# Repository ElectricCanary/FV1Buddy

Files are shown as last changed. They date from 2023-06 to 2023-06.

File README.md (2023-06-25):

# FV1Buddy

THIS PROJECT IS ONLY PARTIALLY WORKING FOR NOW

The FV1Buddy is a Tap Tempo & Clock Module for the Spin Semiconductor FV1 DSP.

You'll find the main code in C, the compiled hex, a datasheet and Altium & Eagle libraries.

Website : https://electric-canary.com/fv1buddy

Support : support@electric-canary.com

The Code, Schematic and PCB manufacturing files are shared under a BY-NC-SA Creative Commons License

Go here for complete license : https://creativecommons.org/licenses/by-nc-sa/4.0/legalcode

Please reach out for licencing if you want to use the code in a commercial product. 

FV1Buddy

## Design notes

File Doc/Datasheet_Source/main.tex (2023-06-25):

\documentclass[a4paper, 10pt]{article}

\usepackage[default]{comfortaa}
\usepackage[utf8]{inputenc}
\usepackage[english]{babel}
\usepackage{graphicx}
\usepackage{geometry}
\usepackage{titlesec}
\usepackage{multicol}
\usepackage{lastpage}
\usepackage{fancyhdr}
\usepackage{array}
\usepackage{multirow, hhline}
\usepackage[table]{xcolor}
\usepackage[hidelinks]{hyperref}
\usepackage{textcomp}

\setlength{\columnseprule}{1pt}
\setlength{\columnsep}{1cm}

\definecolor{lightgray}{gray}{0.85}

\setlength{\arrayrulewidth}{0.35mm}
\setlength{\tabcolsep}{10pt}
\renewcommand{\arraystretch}{1.7}

\fancypagestyle{plain}{%
\fancyhf{} % clear all header and footer fields
\cfoot{\thepage /\pageref{LastPage}}
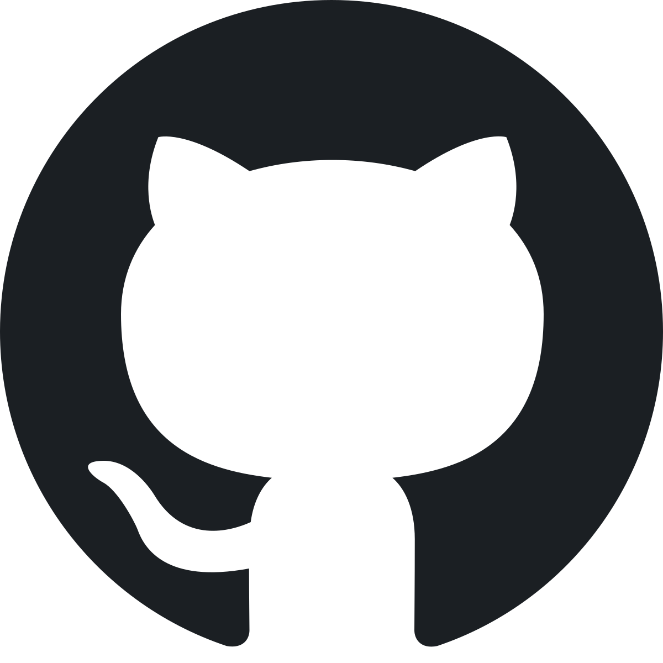
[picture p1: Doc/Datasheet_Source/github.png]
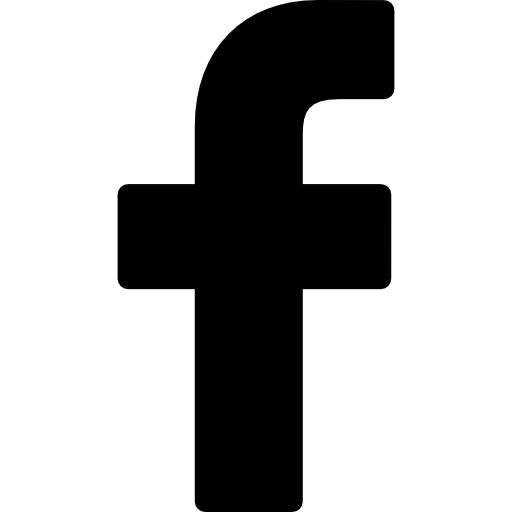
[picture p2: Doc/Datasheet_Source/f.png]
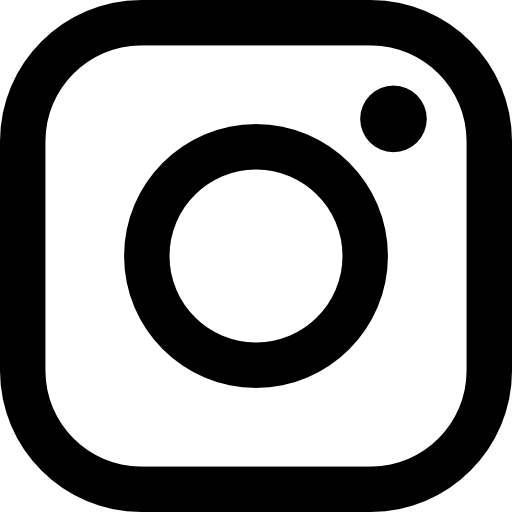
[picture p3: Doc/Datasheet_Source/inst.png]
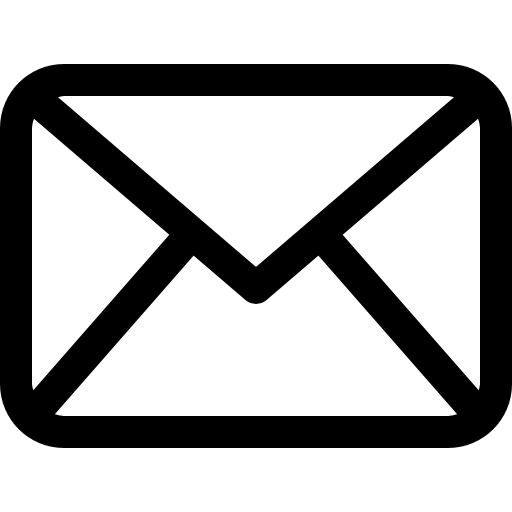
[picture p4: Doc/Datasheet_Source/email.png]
\rfoot{\href{https://github.com/ElectricCanary/FV1Buddy}{}\hspace{8pt}\href{https://www.facebook.com/ElectricCanary}{}\hspace{8pt}\href{https://www.instagram.com/electricanary/}{}\hspace{12pt}\href{mailto:support@electric-canary.com}{}}
\lfoot{\textcolor{black!70}{{\footnotesize\textcopyright Electric Canary - June 2022}}}
\renewcommand{\headrulewidth}{0pt}
\renewcommand{\footrulewidth}{0pt}}

\pagestyle{fancy}
\renewcommand{\headrulewidth}{0pt}
\cfoot{}
\cfoot{\thepage /\pageref{LastPage}}
\rfoot{\href{https://github.com/ElectricCanary/FV1Buddy}{}\hspace{8pt}\href{https://www.facebook.com/ElectricCanary}{}\hspace{8pt}\href{https://www.instagram.com/electricanary/}{}\hspace{12pt}\href{mailto:support@electric-canary.com}{}}
\lfoot{\textcolor{black!70}{{\footnotesize\textcopyright Electric Canary - June 2022}}}
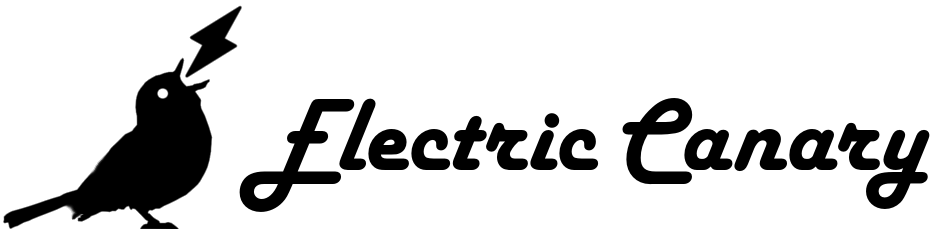
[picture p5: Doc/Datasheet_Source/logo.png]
\rhead{\href{https://electric-canary.com/FV1Buddy}{}}
\lhead{\textbf{{\small\emph{\textcolor{black!70}{FV1Buddy-Datasheet}}}}}

\titleformat*{\section}{\huge\bfseries}
\titleformat*{\subsection}{\LARGE\bfseries}
\titleformat*{\subsubsection}{\Large\bfseries}

\geometry{hmargin=2.5cm,vmargin=2.5cm}
\headheight=35pt

\begin{document}\thispagestyle{plain}
\begin{center}
\begin{Huge}
\vspace*{0.5cm}
\textbf{FV1Buddy - Datasheet}
\rule {0.95\textwidth}{2pt}\\
\end{Huge}
\vspace{1cm}
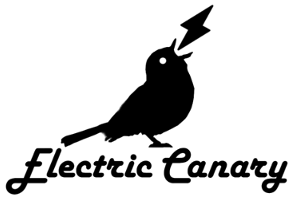
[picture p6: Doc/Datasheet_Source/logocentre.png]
\\
\end{center}
\vspace{1cm}
\begin{multicols}{2}
\section{Introduction}
\bigbreak

FV1Buddy is a Tap Tempo and Clock module for the Spin Semiconductor FV1 DSP.\\

This module is a great option for enabling tap tempo functionality in a FV1 based project.
The tap tempo is intuitive and has 6 different tempo divisions.\\
The clock output can also enhance the DSP's sound, unlike most circuits.\\
Other surprises like the momentary modulation and tempo save let's you enjoy your effects to the fullest.
\vfill\null
\columnbreak

\section{Features}
\bigbreak
\begin{itemize}
\item {Intuitive and Precise Tap Tempo}
\item \hyperref[subsec:tempodiv]{6 Selectable Tempo Divisions} \\  ,  ,  ,  ,  , 
\item \hyperref[sec:clock]{48kHz Clock for Better Audio}
\item \hyperref[sec:temposave]{Tempo EEPROM Save}
\item \hyperref[subsec:ramp]{Ramp Modulation Momentary Effect}
\item \hyperref[sec:pinconfig]{Compact DIP-8 Package}
\item \hyperref[sec:typappsche]{No External Parts}
\item \hyperref[sec:calib]{Adjustable Maximum Delay}
\end{itemize}
\end{multicols}

\newpage
\headheight=35pt
\tableofcontents
\newpage

\section{Pin Configuration}
\label{sec:pinconfig}
\vfill
\begin{center}
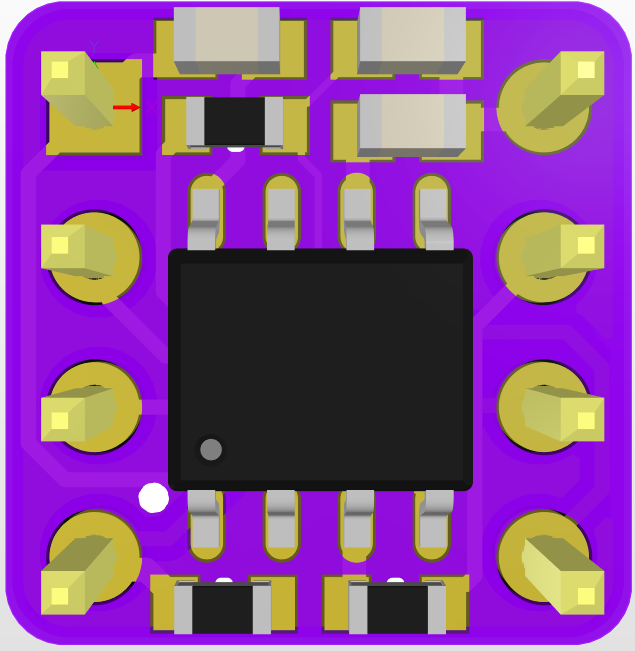
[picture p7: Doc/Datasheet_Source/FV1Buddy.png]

\vfill
\begin{table}[h!]
\begin{tabular}{|m{0.5cm}|m{4.5cm}|m{0.7cm}|m{7.5cm}|}
\hline
\rowcolor{lightgray} \centering {\Large\textbf{N°}} & \centering {\Large\textbf{Name}} & \centering {\Large\textbf{I/O}} & {\Large\textbf{Description}}\\
\hline
\centering 1 & \centering VCC & \centering I & Supply voltage.\\
\hline
\centering 2 & \centering Tap Button & \centering I & Set tempo when connected to ground.\\
\hline
\centering 3 & \centering Delay Time & \centering I & This pin's voltage determines the delay time when there's no tap sequence active.\\
\hline
\centering 4 & \centering Tempo Division Select & \centering I & This pin's voltage determines the tempo division selected.\\
\hline
\centering 5 & \centering Vout & \centering O & This pin can be connected to one of the pot pins of the FV1.\\
\hline
\centering 6 & \centering Clock Out & \centering O & 48kHz clock output for the FV1.\\
\hline
\centering 7 & \centering LED+ & \centering O & LED Indicator Output.\\
\hline
\centering 8 & \centering GND & \centering I & Ground.\\
\hline
\end{tabular}
\caption{Pin Configuration}
\end{table}
\end{center}
\vfill
\newpage

\section{Typical Application Schematic}
\label{sec:typappsche}
\bigbreak
This schematic shows how to implement the FV1Buddy into a simple delay project.
\vfill
\begin{figure} [h!]
\begin{center}

\label{Schem}
\caption{Typical Application Schematic}
\end{center}
\end{figure}
\vfill
\newpage
\section{Absolute Maximum Ratings}
\bigbreak
\begin{table}[h!]
\centering
\begin{tabular}{|c|c|}
\hline
Storage Temperature	& -65°C to +150°C\\
\hline
Operating Temperature & -40°C to +105°C\\
\hline
Voltage on any pin except pin 6	& -0.5V to Vcc + 0.5V\\
\hline
Voltage on Pin 6 & -0.5V to +13.0V\\
\hline
Power Supply Voltage & -0.5V to +6.0V\\
\hline
I/O Pin sink/source current & -40 to 40mA\\
\hline
DC Current for a supply pin & 100.0mA\\
\hline
\end{tabular}
\caption{Absolute Maximum Ratings}
\end{table}
\bigbreak
\bigbreak
\section{DC Characteristics}
\bigbreak
\begin{table}[h!]
\centering
\begin{tabular}{|c|c|c|c|}
\hline
\rowcolor{lightgray}{\Large\textbf{Parameter}} & {\Large\textbf{Min}} & {\Large\textbf{Max}} & {\Large\textbf{Unit}}\\
\hline
Power Supply Voltage & 1.8 & 5.5 & V\\
\hline
Power Supply Current & 5.8 & 7 & mA\\
\hline
\end{tabular}
\caption{DC Characteristics}
\end{table}
\bigbreak
For any other DC characteristics please refer to the ATtiny402 \href{http://ww1.microchip.com/downloads/en/DeviceDoc/ATtiny202-402-AVR-MCU-with-Core-Independent-Peripherals_and-picoPower-40001969A.pdf}{\underline{datasheet}} (p.476).
\bigbreak
\bigbreak
\section{Specifications}

\begin{table}[h!]
\centering
\begin{tabular}{|c|c|c|c|}
\hline
\rowcolor{lightgray}{\Large\textbf{Parameter}} & {\Large\textbf{Min}} & {\Large\textbf{Max}} & {\Large\textbf{Unit}}\\
\hline
Delay Time & 0 & 1000 & ms\\
\hline
PWM frequency & - & 20 & kHz\\
\hline
Clock frequency & - & 48 & kHz\\
\hline
All Potentiometer/Toggle Input & 0 & Vcc & V\\
\hline
\end{tabular}
\caption{Specifications}
\end{table}

All specifications tested at VCC = 3.3V.

\section{Power Supply}
\bigbreak
In order to function properly the module \textbf{must} be powered from the same 3.3V power supply than the FV1. Any voltage difference between the FV1Buddy and the FV1 power supplies will introduce some time error between the tap tempo and the delay.
A 0.1$\mu$F capacitor between Vcc and GND is already included in the module. Additional decoupling shouldn't be necessary.\\

\section{Calibration}
\label{sec:calib}
\bigbreak
The FV1Buddy comes with a 1000ms maximum delay. However some FV1 delay programs have a smaller maximum delay to accommodate the FV1 performance characteristics.\\
The FV1Buddy module maximum delay can be adjusted to 700, 800, 900 or 1000 ms.\\

To to calibrate the FV1Buddy, follow these instructions :\\
\begin{itemize}
\item Make sure the module is powered down.
\item Position the Time potentiometer to the desired maximum delay.
\item Minimum for 700ms, 10 o'clock for 800ms, 2 o'clock for 900ms, maximum for 1000ms.
\item Press the Tap Button.
\item Power Up the FV1Buddy while keeping the Tap Button Pressed.
\item Keep the button pressed while the Tempo LED blinks twice.
\item Release the Tap Button.
\item The LED blinks twice, the module is now calibrated to the new maximum delay.\\
\end{itemize}

\newpage
\section{Controls}
\subsection{Tap Tempo Button}
\bigbreak
This input is only compatible with a momentary switch.
The debounce is handled by software and with a 0.1$\mu$F capacitor in parallel to the Switch. No extra external components have to be used.\\

The program starts counting milliseconds after the first press. The delay time tapped is in effect right after the second press of the tap button. After the second press of the tap button, every following tap in the sequence is averaged in order to reach easily the desired tempo. 

If the button is not pressed again after a certain time ,the timer is reset and the tap sequence is ended. When a tap sequence has started, it will take 2 pulsations to be finished (the LED will start blinking on its own).\\

If the tap tempo button is pressed only once, the tap sequence will be aborted after the reset time passed.\\
The reset time follows this equation: $\frac{Max Delay}{Tempo Div Mult} + 800 = Reset Time (ms)$\\

Max Delay is either 1000, 900, 800 or 700ms. Tempo Div Mult is the multiplier of the current time division (1, 0.75, 0.5, 0.33, 0.25, 0.17).\\

When the tap tempo is active, the tempo LED will blink with the rhythm you tapped, regardless of the selected tempo division.\\

\subsection{Delay Time}
\label{subsec:delaytime}
\bigbreak
This input is to voltage control the delay time. This input will control the delay time until you activate the tap tempo. While the delay time is controlled by this input, the Tempo LED and will stay on.\\

To take back control from the Tap Tempo, you just need to modify this input's voltage by 7\%. Typically, you would use a Potentiometer for the delay time control. The recommended potentiometer value is 10k$\Omega$ or above, to avoid having too much current going through the pin.\\

You can add a 0.1$\mu$F capacitor between the input and ground for smoother time changes.\\

\subsection{Tempo Division Select}
\label{subsec:tempodiv}
\bigbreak
Six different tempo division are accessible with this input. To access every time division a SPDT On-Off-On toggle switch is required.\\

The first three time divisions are fourth, dotted eighth and eighth. The last three time divisions are accessed by first pressing the tap button and then changing the toggle position while the tap button is pressed. The press will not count as a press for the tap tempo. The three last time divisions are triplet, sixteenth and sextuplet.\\

The time divisions are selected by changing the Tempo Div Select Pin's voltage (Pin 4).\\

If the time division is changed while the Tap Tempo is active, the delay time will be changed accordingly instantly.\\

On the module, the middle position is accessed by putting a 27k$\Omega$ resistor between pin 4 and ground.\\

\subsection{Ramp Modulation}
\label{subsec:ramp}
\bigbreak
A ramp modulation can be activated if the tap button is pressed more than 2 seconds.\\
The ramp will begin to ascend then will descend once the max delay is achieved.\\
The modulation speed can be controlled by moving the Time Potentiometer accordingly. The movements won't be taken into account once you release the tap button.\\

\section{Tempo Save}
\label{sec:temposave}
\bigbreak
When you tap a tempo it is saved on the FV1Buddy's EEPROM. This means that if you power down the FV1Buddy while a tap sequence is active, the module will resume this sequence when powered up. This is true even if some parameters are moved when the FV1Buddy is powered down.\\

\section{Vout}
\label{sec:vout}
\bigbreak
The voltage output of pin 5 is to be connected to one of the "pot" inputs of the FV1 DSP (pins 20, 21 \& 22).\\
This analog voltage is achieved by passing a 20kHz PWM through an onboard RC low-pass filter. The low-pass filter is composed of a 10k$\Omega$ resistor and a 10$\mu$F capacitor.\\

\section{Clock Output}
\label{sec:clock}
\bigbreak
The clock output of pin is to be connected to the "X1" pin of the FV1 DSP (pin 10).\\
The clock has a frequency of 48kHz and will expand the bandwidth of the DSP up to 24kHz comparing to a 15kHz bandwidth with an oscillator.\\
This change will be pretty noticeable and help you fully appreciate your audio effects.\\

\section{Tempo LED}
\label{sec:led}
\bigbreak
When the delay time is controlled by the Time Potentiometer the LED will stay on.\\
When tapping a tap sequence, the LED will blink exactly when you press the tap button, beginning with the second press.\\
When the Tap Tempo is active, the tempo LED will blink in sync with the tempo you tapped regardless of the tempo division selected.\\
A 1k$\Omega$ current limiting resistor is included on the module.

\end{document}

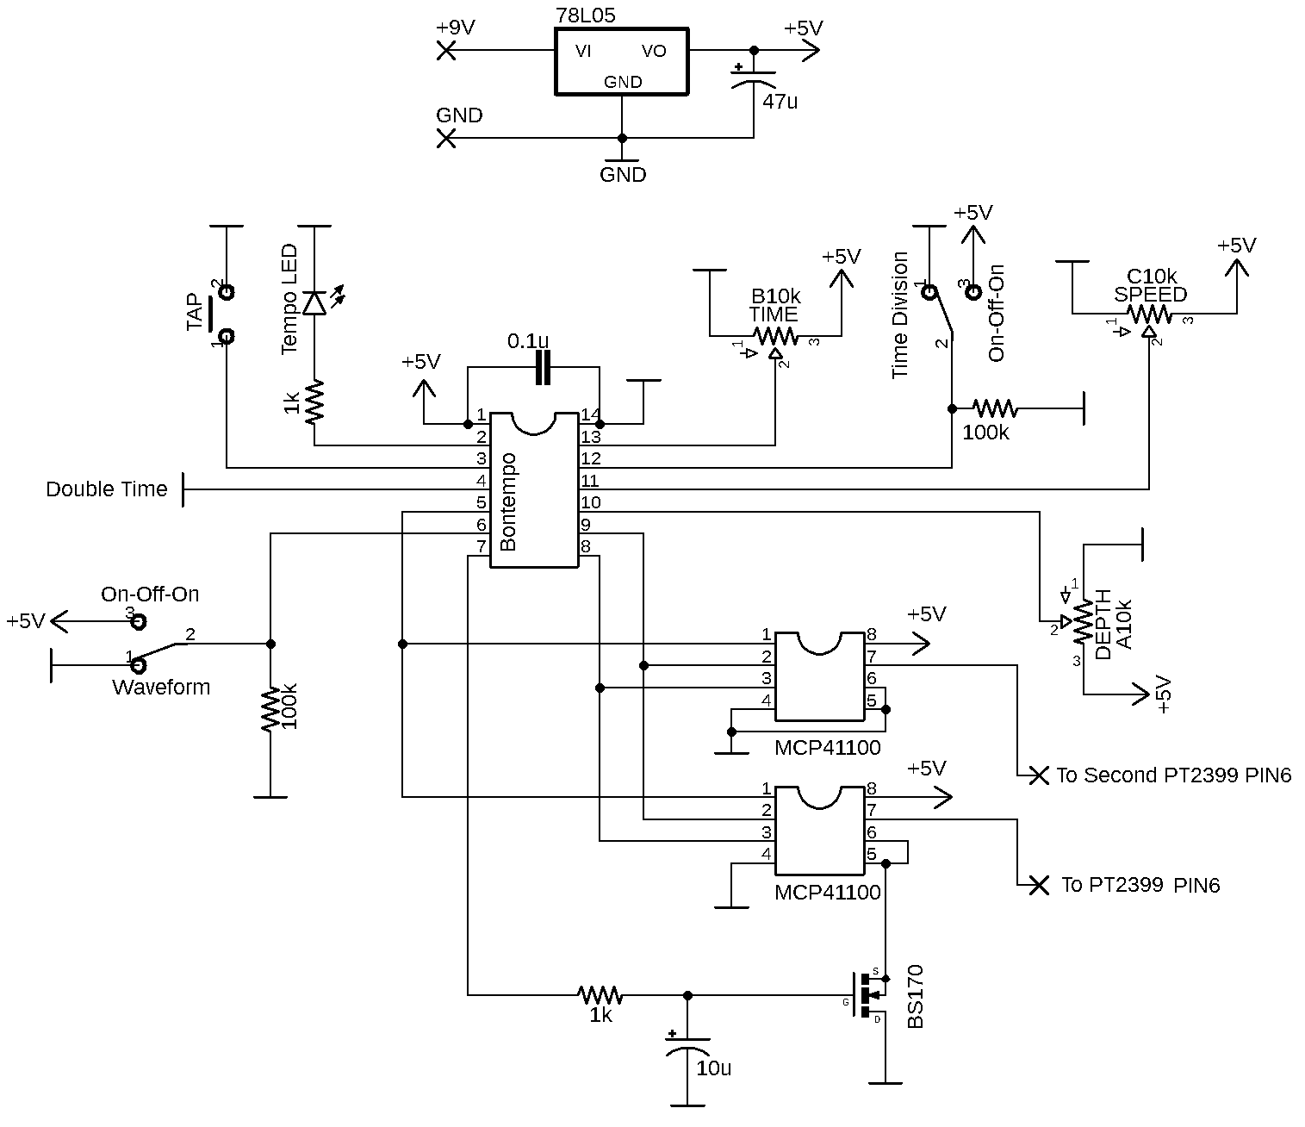
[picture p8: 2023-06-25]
Doc/Datasheet_Source/DualSchematic.png

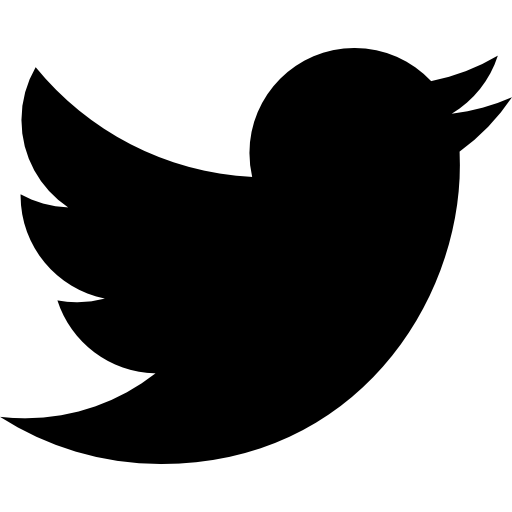
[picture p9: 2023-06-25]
Doc/Datasheet_Source/twitter.png

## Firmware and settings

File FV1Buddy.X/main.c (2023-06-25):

/* 
 * FV1 Buddy
 * January 2022
 * by Antoine Ricoux for Electric Canary
 * 
 *  https://electric-canary.com/FV1Buddy
 *  support@electric-canary.com
 * 
 * This code is an ATtiny402 Tap Tempo & Clock for the Spin Semiconductors FV1 DSP
 * It can be calibrated for 700, 800, 900 & 1000ms delays.
 * 
 * Pinout:
 * 1: VDD
 * 2: 48kHz Clock Output
 * 3: LED+ Output
 * 4: Time Potentiometer Analog Input
 * 5: Tempo Division Switch (On-Off-On) Analog Input
 * 6: Momentary Tap Tempo Button Input
 * 7: PWM Output
 * 8: GND
 * 
 * This code is shared shared under a BY-NC-SA Creative Commons License
 * Go here for complete license : https://creativecommons.org/licenses/by-nc-sa/4.0/legalcode
 */
#include <avr/io.h>
#include <avr/interrupt.h>
#define F_CPU 20000000UL
#include <util/delay.h>
#include <avr/eeprom.h>
#include <stdlib.h>

#define CLK_PIN 6
#define PWM_PIN 3
#define TAP_PIN 0
#define LED_PIN 7
#define POT_PIN 1
#define DIV_PIN 2
#define DEBOUNCE_TIME 900
#define EEPROM_TAP 0
#define EEPROM_TEMPO 1
#define EEPROM_DELAYMAX 3

volatile uint16_t pot;
volatile uint16_t divsw;
volatile uint16_t pwm = 500;
volatile uint16_t ms;
volatile uint16_t ledms;

//This set of fuses will deactivate the reset, it will be impossible to reprogram the chip without high voltage programming
FUSES = {
	.WDTCFG = 0x00, // WDTCFG {PERIOD=OFF, WINDOW=OFF}
	.BODCFG = 0x00, // BODCFG {SLEEP=DIS, ACTIVE=DIS, SAMPFREQ=1KHz, LVL=BODLEVEL0}
	.OSCCFG = 0x02, // OSCCFG {FREQSEL=20MHZ, OSCLOCK=CLEAR}
	.TCD0CFG = 0x00, // TCD0CFG {CMPA=CLEAR, CMPB=CLEAR, CMPC=CLEAR, CMPD=CLEAR, CMPAEN=CLEAR, CMPBEN=CLEAR, CMPCEN=CLEAR, CMPDEN=CLEAR}
	.SYSCFG0 = 0xF2, // SYSCFG0 {EESAVE=CLEAR, RSTPINCFG=GPIO, CRCSRC=NOCRC}
	.SYSCFG1 = 0x07, // SYSCFG1 {SUT=64MS}
	.APPEND = 0x00, // APPEND {APPEND=User range:  0x0 - 0xFF}
	.BOOTEND = 0x00, // BOOTEND {BOOTEND=User range:  0x0 - 0xFF}
};

void IO_Init(void)
{
  //PWM & LED as outputs
  PORTA.DIRSET = (1<<PWM_PIN) | (1<<LED_PIN) | (1<<CLK_PIN);
  //pull up for div switch & tap button
  PORTA_PIN0CTRL |= PORT_PULLUPEN_bm;
  PORTA_PIN2CTRL = PORT_ISC_INPUT_DISABLE_gc | PORT_PULLUPEN_bm;
  PORTA_PIN1CTRL = PORT_ISC_INPUT_DISABLE_gc;
}

void ADC_Config(void)
{
  //reference to VCC with the right sampling capacitor 
  ADC0.CTRLC = ADC_SAMPCAP_bm | ADC_REFSEL_VDDREF_gc | ADC_PRESC_DIV32_gc;
  //ADC0.CTRLB = ADC_SAMPNUM_ACC32_gc;
  //Start with ADC channel 1
  ADC0.MUXPOS = ADC_MUXPOS_AIN2_gc;
  //enable result ready interrupt
  ADC0.INTCTRL = ADC_RESRDY_bm;
  //10bits freerun & enable
  ADC0.CTRLA |= ADC_ENABLE_bm | ADC_RESSEL_10BIT_gc | ADC_FREERUN_bm;
  //Start conversion
  ADC0.COMMAND = ADC_STCONV_bm;
}

ISR(ADC0_RESRDY_vect)
{
  switch(ADC0.MUXPOS)
  {
    case ADC_MUXPOS_AIN1_gc:
        divsw = ADC0.RES;
        ADC0.MUXPOS = ADC_MUXPOS_AIN2_gc;
    break;
    
    case ADC_MUXPOS_AIN2_gc:
        pot = ADC0.RES;
        ADC0.MUXPOS = ADC_MUXPOS_AIN1_gc;
    break;
    
    default:
        ADC0.MUXPOS = ADC_MUXPOS_AIN1_gc;
    break;
  }
    ADC0.INTFLAGS = ADC_RESRDY_bm;
}

//ms timer for tap tempo
void TCA_Config(void)
{
  //Enable interrupts
  sei();
  //Enable PWM output 0 (PA3), single slope PWM
  TCA0.SINGLE.CTRLB |= TCA_SINGLE_WGMODE_SINGLESLOPE_gc | TCA_SINGLE_CMP0EN_bm;
  //Set period to 1000 (20kHz for 20MHz clock)
  TCA0.SINGLE.PER = 999;
  TCA0.SINGLE.CMP0 = 500; 
  //Enable overflow interrupt
  TCA0.SINGLE.INTCTRL |= TCA_SINGLE_OVF_bm;
  //Enable timer
  TCA0.SINGLE.CTRLA = TCA_SINGLE_ENABLE_bm;
}

ISR(TCA0_OVF_vect)
{
  TCA0.SINGLE.CMP0BUF = pwm;
  static uint8_t count;
  count++;
  if (count >= 20)
  {
    count = 0;
    ms++;
    ledms++;
  }
  
  //Clear interrupt flag
  TCA0.SINGLE.INTFLAGS = TCA_SINGLE_OVF_bm;
}

//32kHz Timer for FV-1
void TCB_Config(void)
{
    //8bit PWM Mode, enable output pin
    TCB0.CTRLB = TCB_CNTMODE_PWM8_gc | TCB_CCMPEN_bm;
    //Set period at 208 (5MHz/153 = 32 680Hz)
    TCB0.CCMPL = 153;
    //Set duty cycle at 50%
    TCB0.CCMPH = 127;
    //Enable timer and dividing clock by 2 (10MHz)
    TCB0.CTRLA = TCB_CLKSEL_1_bm | TCB_ENABLE_bm;
}

uint8_t debounce(void)
{
    if (!(PORTA.IN & (1<<TAP_PIN)))
    {
        _delay_us(DEBOUNCE_TIME);
        if (!(PORTA.IN & (1<<TAP_PIN)))
        {
            return(1);
        }
        else
        {
            return(0);
        }
    }
    
    else
    {
        return(0);
    }
}

void blink(void)
{
    PORTA.OUTTGL = (1<<LED_PIN);
    _delay_ms(150);
    PORTA.OUTTGL = (1<<LED_PIN);
    _delay_ms(150);
}

uint16_t calib(void)
{
    uint16_t count = 0;
    
    if (debounce())
    {
        while(debounce())
        {
            _delay_us(1000 - DEBOUNCE_TIME);
            count++;
            if (count >= 5000)
            {
                PORTA.OUTCLR = (1<<LED_PIN);
                blink();
                blink();
                for (uint16_t c = 0; c < 4000; c++ )
                {
                    _delay_us(1000 - DEBOUNCE_TIME);

                    if (!debounce())
                    {
                        blink();
                        blink();
                        return(((pot>>8)+7)*100);
                    }
                }
            }
        }
    }
    
    else
    {
        if(eeprom_read_word((uint16_t*)EEPROM_DELAYMAX) > 1000)
        {
            eeprom_update_word((uint16_t*)EEPROM_DELAYMAX,1000);
            return(1000);
        }
        else
        {
            return(eeprom_read_word((uint16_t*)EEPROM_DELAYMAX));
        }
    }
}

int main(void)
{
  //Unlocking protected registers and setting main clock to 20MHz
  CPU_CCP = CCP_IOREG_gc;
  CLKCTRL.MCLKCTRLB = 0;
  CLKCTRL.MCLKLOCK |= CLKCTRL_LOCKEN_bm;
  
  uint8_t tap = eeprom_read_byte((uint8_t*)EEPROM_TAP); //1 for tap tempo control, 0 for pot control
  uint8_t laststate = 0; //laststate of tap button
  uint8_t nbtap = 0; //number of taps
  uint8_t tapping = 0; //1 if user is currently tapping
  uint16_t mstempo = eeprom_read_word((uint16_t*)EEPROM_TEMPO); //Current tempo in ms
  uint16_t divtempo = 500; //Current tempo in ms multiplied by divmult
  float divmult = 1; //Multiplier for tempo division
  uint16_t previousdiv = 60000;
  uint16_t previouspot;
  uint8_t updown;
  
  //enable interrupts
  sei();
  IO_Init();
  TCA_Config();
  TCB_Config();
  ADC_Config();
  uint16_t delaymax = calib(); //Maximum delay in ms allowed
  
  if (tap == 1)
  {
      previouspot = pot;
  }
  else
  {
      previouspot = 60000;
  }
  
  _delay_ms(500);
  
    while (1)
    {
        //TEMPO DIV
        if (abs(previousdiv - divsw) > 300)		//if first time or if div toggle changed position : update div
		{
			if (debounce() == 0)	//if tap button not pressed while changing 3 first div
			{
				if (divsw <= 100){divmult = 1;}	//fourth
			
				if (divsw > 101 && divsw < 900){divmult = 0.75;}	//dotted eighth
				
				if (divsw >= 900){divmult = 0.5;}	//eighth
			}
			
			if (debounce() == 1)	//if tap button pressed while changing 3 last div
			{
				if (divsw <= 100){divmult = 0.333333;}	//triplet
				
				if (divsw > 101 && divsw < 900){divmult = 0.25;}	//sixteenth
				
				if (divsw >= 900){divmult = 0.1666666;}	//sextuplet
				
				nbtap = 0;			//don't count press as tap
				tapping = 0;
				ms = 0;
				laststate = 1;
			}
			
			if (tap == 1)	//if in tap control, update pwm value
			{
				divtempo = round(mstempo * divmult);
				pwm = divtempo;
			}
			
			ledms = 0;
			previousdiv = divsw;	//reseting previousdiv to detect next move
		}
        
        //TIME POT
        //if pot move of more than 7%, changing to pot control
        if ((tap == 1 && tapping == 0 && abs(previouspot-pot) >= 72) || (tap == 0 && tapping == 0 && abs(previouspot-pot) >= 1))
		{
			pwm = pot * (0x3FF/delaymax);
			previouspot = pot;
			tap = 0;
            eeprom_update_byte((uint8_t*)EEPROM_TAP,0);
		}
        
        //TAP TEMPO
        
        if (debounce() && laststate==0 && nbtap==0) //first tap
		{
			TCA0.SINGLE.CNT = 0;			//starts counting
			ms=0;
			nbtap++;
			laststate = 1;
			tapping = 1;
		}
        
		if (nbtap > 1 && !debounce() && laststate==0) //if too long between taps  : resets
		{
            if (ms > (1.5*mstempo))
            {
                eeprom_update_byte((uint8_t*)EEPROM_TAP,1);
                eeprom_update_word((uint16_t*)EEPROM_TEMPO,mstempo);
            }
            
            if (ms > (3*mstempo))
            {
                ms = 0;
                nbtap = 0;
                tapping = 0;
            }
		}
		
		if (nbtap == 1 && ms > ((delaymax/divmult) + 800) && !debounce() && laststate==0) //if tapped only once, reset once the max tempo for the div + 800ms passed
		{
			ms = 0;
			nbtap = 0;
			tapping = 0;
		}
		
		if (!debounce() && laststate == 1)	//release tap button
		{
			laststate = 0;
			PORTA.OUTCLR = (1<<LED_PIN);
            previouspot = pot;
            previousdiv = divsw;
		}
		
		if (debounce() && laststate==0 && nbtap!=0 && ms >= 100) //not first tap
		{
			if (TCA0.SINGLE.CNT >= 500){ms++;}	//round up value if timer counter more than 500µs
			
			if (nbtap == 1)		//if second tap, tempo = time elapsed between the 2 button press
			{
				divtempo = ms * divmult;
				mstempo = ms;
			}
			
			else		//if not second tap, average every tap
			{
				divtempo = (divtempo + (ms*divmult)) / 2;
				mstempo = (mstempo + ms)/2;
			}
            
            pwm = divtempo;
            
			nbtap++;                //updating number of tap and last state of tap button
			laststate = 1;
			TCA0.SINGLE.CNT = 0;    //reseting counter and ms
			ms = 0;
			ledms = 0;
			tap = 1;                //now in tap control mode
			PORTA.OUTSET = (1<<LED_PIN);
		}
        
        // RAMP
        if (debounce() && ms >= 2000 && laststate==1)	//if button pressed more than 2s
		{
            while (debounce())
            {
                if(updown == 0)
                {
                    divtempo += 1;
                }
                
                else
                {
                    divtempo -= 1;
                }
                
                pwm = divtempo;
                
                if (divtempo == 0 || divtempo == delaymax) 
                {
                    updown ^= 1;
                    PORTA.OUTTGL = (1<<LED_PIN);
                }
                
                for (uint16_t i = 0; i < pot; i++)
                {
                    _delay_us(1);
                }
            }
            if (tap == 1)
            {
                divtempo = mstempo * divmult;
                pwm = divtempo;
            }
			else
            {
                pwm = pot * (0x3FF/delaymax);
            }
            updown = 0;
            previouspot = pot;
        }
        
        //---------LED CONTROL
        if (tap != 1 && tapping == 0)
        {
            PORTA.OUTSET = (1<<LED_PIN);
        }
        
        if (tapping == 1 && nbtap == 1 && laststate == 1)//keep the light off when long button press
        {
            PORTA.OUTCLR = (1<<LED_PIN);
        }	
        
		if (tap == 1 && tapping == 0 && !debounce())
		{	
			if (ledms >= mstempo - 4)	//turns LED on every downbeat
			{
				ledms = 0;
				PORTA.OUTSET = (1<<LED_PIN);
			}
		
			if (ledms >= 8)			//turns LED off 4ms after downbeat
			{
				PORTA.OUTCLR = (1<<LED_PIN);
			}
		}
    }
}
